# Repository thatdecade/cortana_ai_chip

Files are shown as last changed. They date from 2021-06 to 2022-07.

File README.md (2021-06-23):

# Cortana AI Chip
Neopixel animated cortana chip with USB display stand.

Blog Post: https://www.westaby.net/2021/06/cortana-data-chip-and-display-stand/

Kits for sale: https://www.etsy.com/shop/WestabyElectronics

https://user-images.githubusercontent.com/6401110/123125386-17de3000-d40e-11eb-948b-370709867ea7.MOV

## Instructions: 
Choose which version you want to make, Trinket or Wemos.  Then print the associated 3D files and wire it up.

More build notes on the related pages.

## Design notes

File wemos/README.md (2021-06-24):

# WORK IN PROGRESS!!!!

I have not built this version yet.

# Wemos Build Instructions

This folder is for building a Cortana AI Chip with an WEMOS D1 Mini dev board.

[IMAGE]

## Part List:
* WEMOS D1 Mini https://amzn.to/3qwWNKp
* Neopixel jewel https://amzn.to/3gKQ6ko
* Pushbutton https://amzn.to/3x0Akra
* Magnet Connectors [TBD]

* Silver PLA Filament https://amzn.to/3vN5HnV
* Gray Glitter PLA Filament https://amzn.to/3d2W3ab
* Transparent PLA Filament https://amzn.to/3xEOMFm

We are a participant in the Amazon Services LLC Associates Program, an affiliate advertising program designed to provide a means for us to earn fees by linking to Amazon.com and affiliated sites.

## 3D Printing:

The Cortana Data Chip’s 3D model was designed by Dylan Powell. I modified the Halo Cortana Chip to fit the neopixel jewel and magnet pin connector. Model is prescaled to 125%. Download: https://www.thingiverse.com/thing:4891701

I printed the Data Chip with 0.20 layer height as a color change job at 2.80mm. Dark grey and then Silver.

## Assembly and Wiring:
* WEMOS D0 to Neopixel Data In
* WEMOS D1 to Button LED
* WEMOS D2 to Button Switch

The magnet connector has straight pins (not solder cup friendly).  Recommend using some spare perfboard as a breakout or some 30 AWG Wrapping Wire around the pins using a wire wrap tool, then soldering.  More info: https://learn.sparkfun.com/tutorials/working-with-wire/how-to-use-a-wire-wrap-tool

Since the magnet connector is not keyed, it is possible to connect the cortana ai chip in backwards and reverse all the pins to the neopixel.  To prevent burnout, place the V+ pin in the center and a 100k ohm resistor on the data pin.  The breakout board in the pcb folder does this.

## Arduino:

TBD

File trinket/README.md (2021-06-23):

# Trinket Build Instructions

This folder is for building a Cortana AI Chip with an Adafruit Trinket Mini 5V dev board.

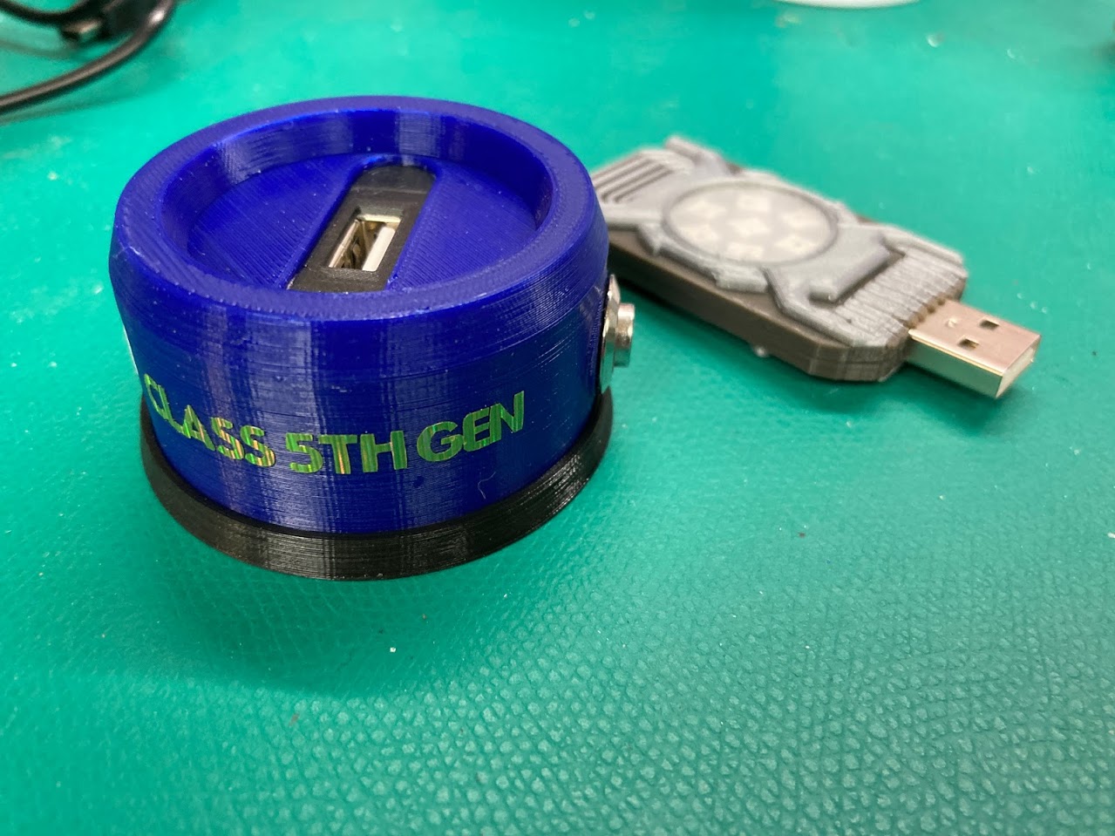
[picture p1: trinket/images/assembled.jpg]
 

## Part List:
* Adafruit trinket https://amzn.to/2SXYDr3
* Neopixel jewel https://amzn.to/3gKQ6ko
* Pushbutton https://amzn.to/3x0Akra
* USB Connectors https://amzn.to/3qiJgWt

* Silver PLA Filament https://amzn.to/3vN5HnV
* Gray Glitter PLA Filament https://amzn.to/3d2W3ab
* Transparent PLA Filament https://amzn.to/3xEOMFm

We are a participant in the Amazon Services LLC Associates Program, an affiliate advertising program designed to provide a means for us to earn fees by linking to Amazon.com and affiliated sites.

## 3D Printing:

The Cortana Data Chip’s 3D model was designed by Dylan Powell. I modified the Halo Cortana Chip to fit the neopixel jewel and usb plug. Model is prescaled to 125%. Download: https://www.thingiverse.com/thing:4891701

I printed the Data Chip with 0.20 layer height as a color change job at 2.80mm. Dark grey and then Silver.

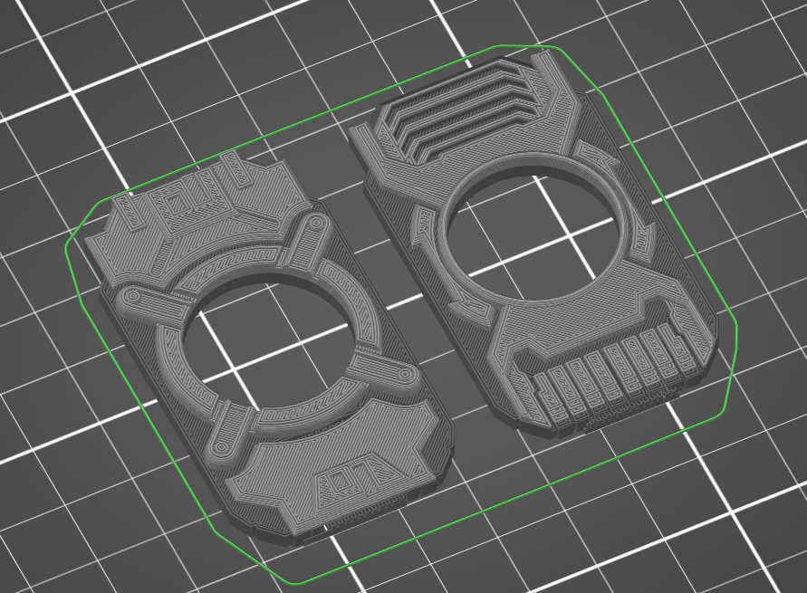
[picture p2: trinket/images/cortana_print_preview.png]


## Assembly and Wiring:
* Trinket #0 to Neopixel Data In
* Trinket #1 to Button LED
* Trinket #2 to Button Switch

I wired the neopixel through the USB socket.  V+ and GND I kept on pins 1 and 4, neopixel data wire on one of the data pins.  This ensures that if the USB is plugged into a real USB port, nothing will break.

## Arduino:
The code was based on an adafruit example for the trinket. I wrote about 10 animations, inspired by my previous energy sword builds.

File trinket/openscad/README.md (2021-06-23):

# Printing

You can print the objects as-is.  They are prescaled to 125% with cutouts for the USB and NeoPixel Jewel.

To remix using openscad, you will need the original objects from here: https://www.thingiverse.com/thing:1114763

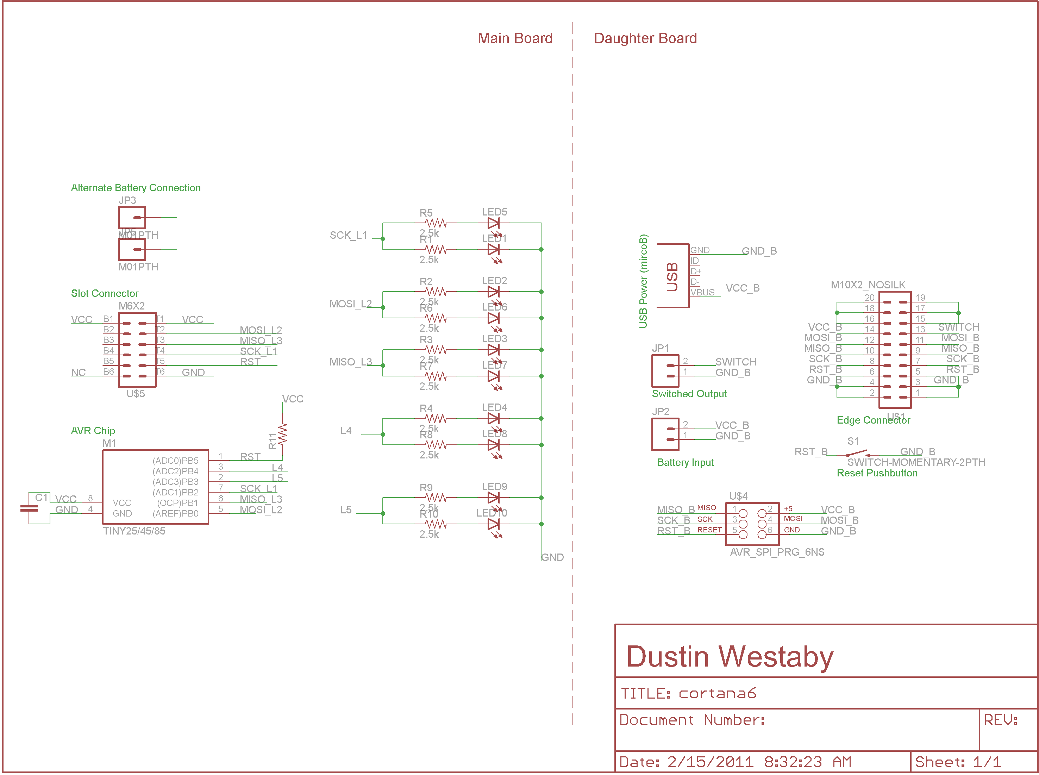
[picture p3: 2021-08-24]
attiny/schematic.png

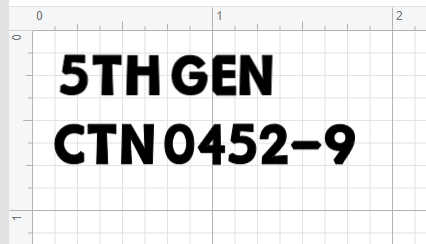
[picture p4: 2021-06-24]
trinket/images/stickers.png

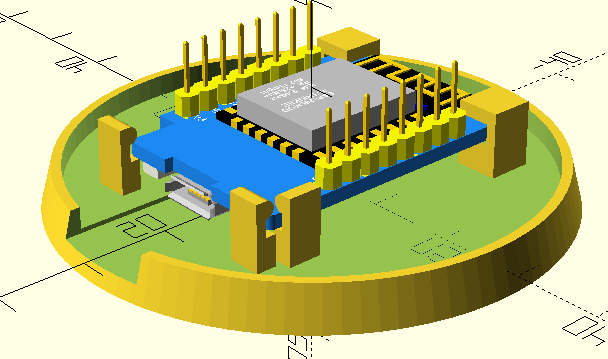
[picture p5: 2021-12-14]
wemos/openscad/cortana_stand_render_2.png

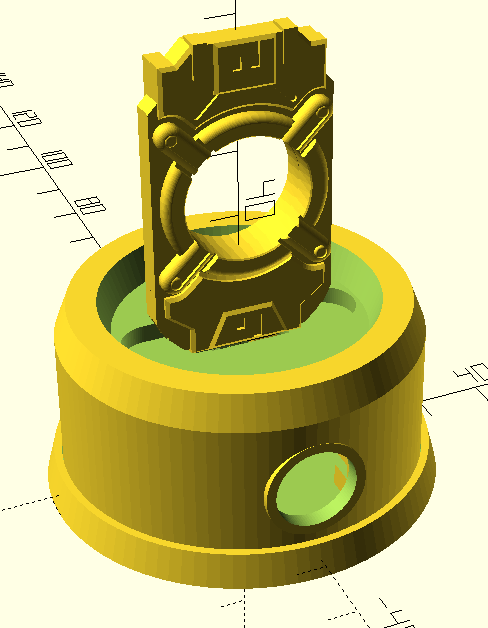
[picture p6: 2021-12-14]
wemos/openscad/cortana_stand_render_1.png

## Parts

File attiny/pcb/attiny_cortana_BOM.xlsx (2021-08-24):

Comment | Designator | Footprint | JLCPCB Part #（optional）
0.1uF | C2 | 0402 | C696352
10k ohm | R12 | 0402 | C25744
100 ohm | R1-11 | 0402 | C25076
Blue LED | LED1-10 | LED_0603 | C72041
Attiny45-20SU | U1 | 8-SOIC | C62689

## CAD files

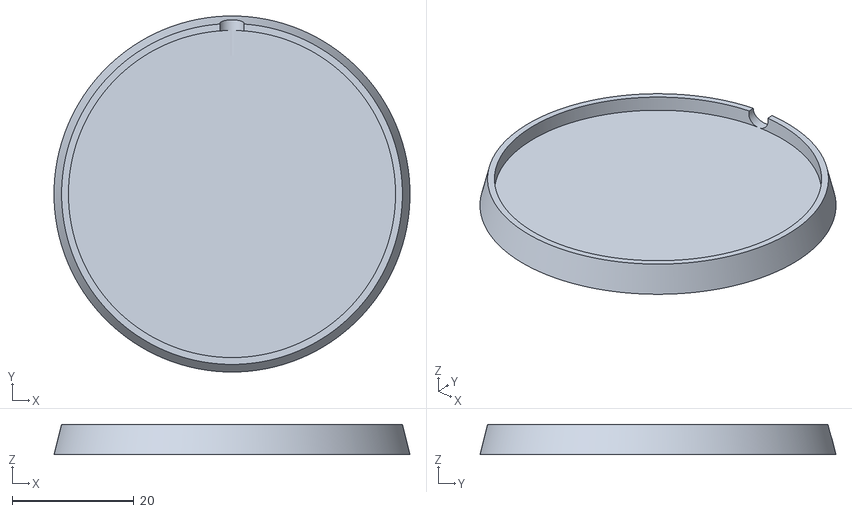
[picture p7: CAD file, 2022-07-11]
attiny/openscad/attiny_cortana_ai_chip_stand_bottom.stl
58.5 x 58.5 x 5.00

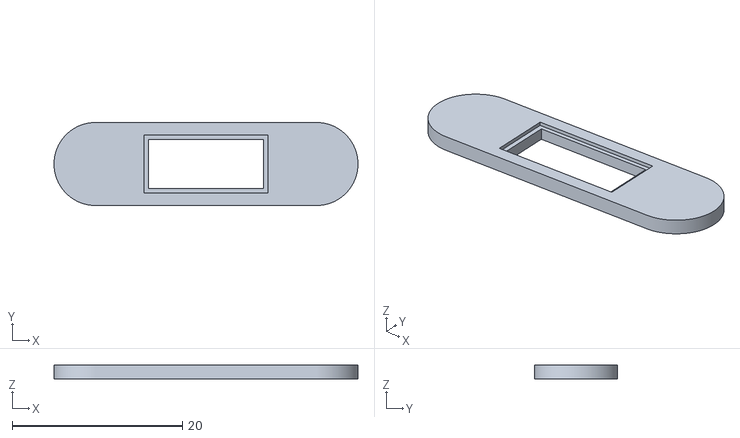
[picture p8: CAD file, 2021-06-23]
trinket/openscad/cortana_ai_chip_stand_usb_inset.stl
35.7 x 9.75 x 1.60

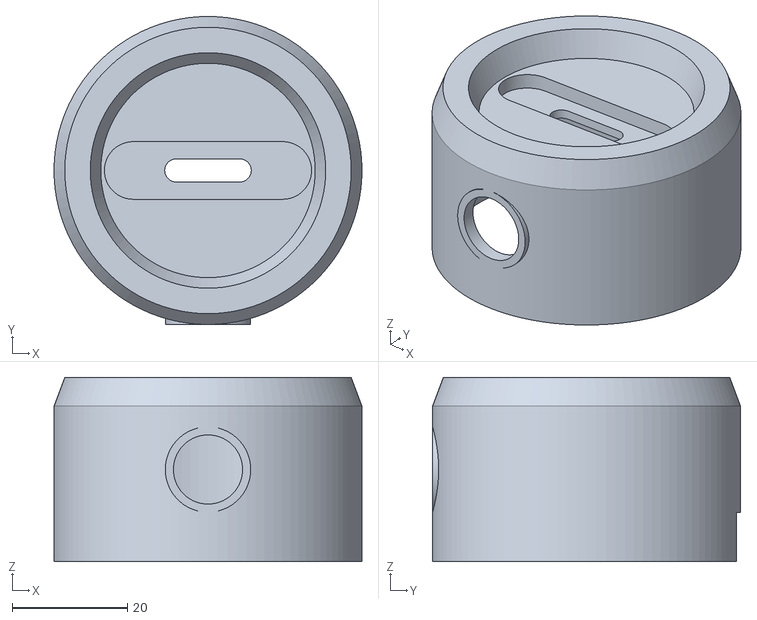
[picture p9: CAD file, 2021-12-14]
wemos/openscad/cortana_ai_chip_stand_top.stl
53.5 x 53.5 x 32.0

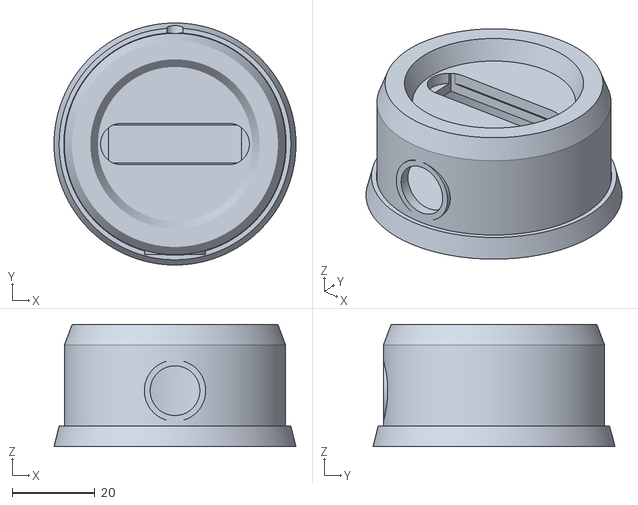
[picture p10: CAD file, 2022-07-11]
attiny/openscad/attiny_cortana_ai_chip_stand.stl
58.5 x 58.5 x 29.5

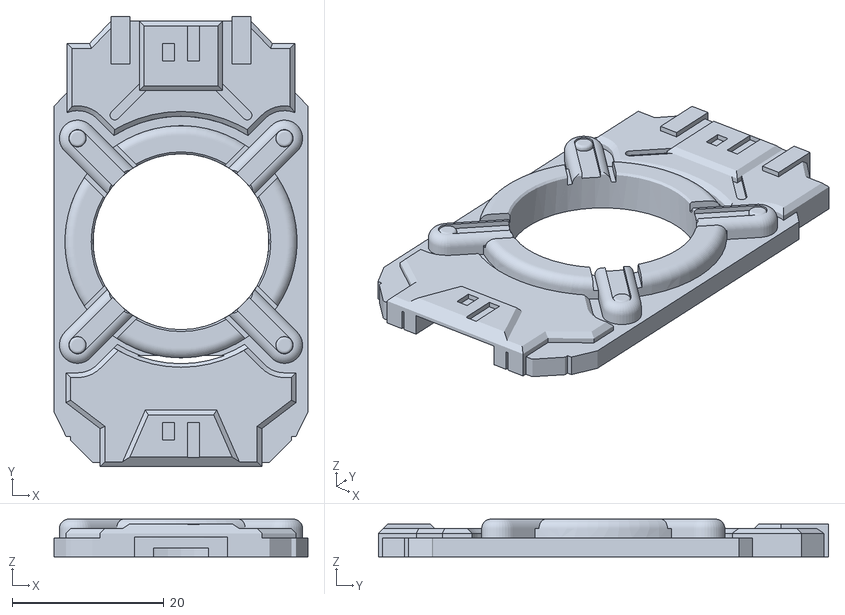
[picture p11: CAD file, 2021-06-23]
trinket/openscad/cortana_ai_chip_usb_125_scale_bottom.stl
33.5 x 59.3 x 5.00

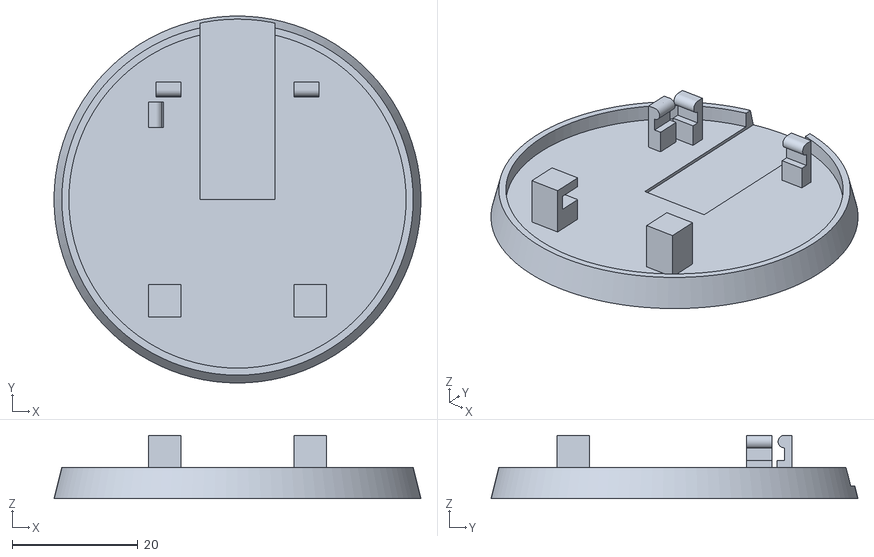
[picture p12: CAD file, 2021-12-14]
wemos/openscad/cortana_ai_chip_stand_bottom.stl
58.5 x 58.5 x 10.1

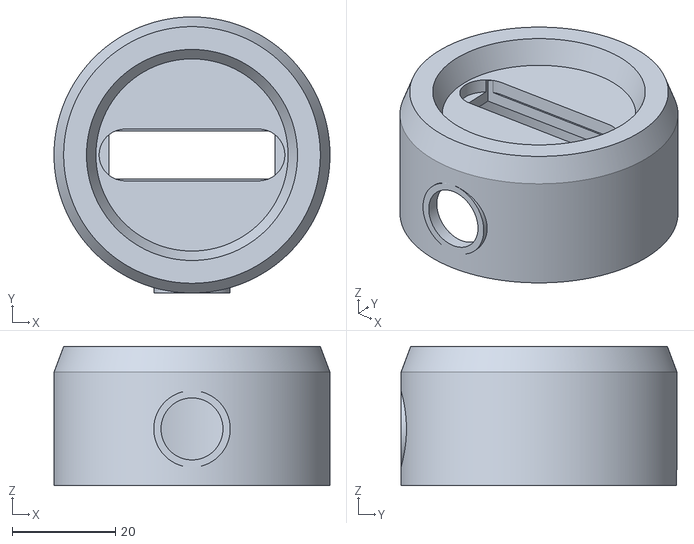
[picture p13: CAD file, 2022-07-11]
attiny/openscad/attiny_cortana_ai_chip_stand_top.stl
53.5 x 53.5 x 27.0

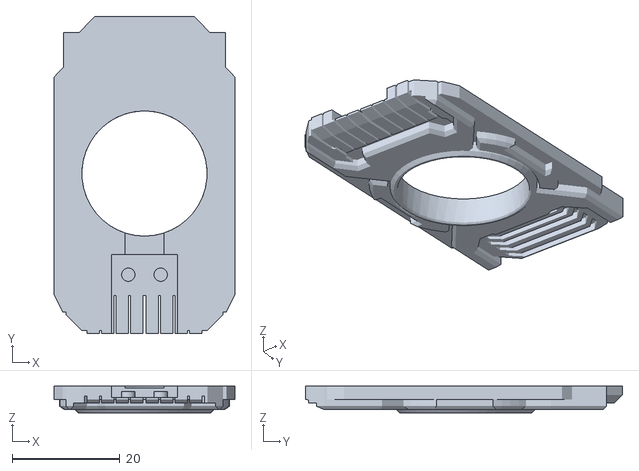
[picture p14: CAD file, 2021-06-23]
trinket/openscad/cortana_ai_chip_usb_125_scale_top.stl
33.5 x 58.7 x 5.00

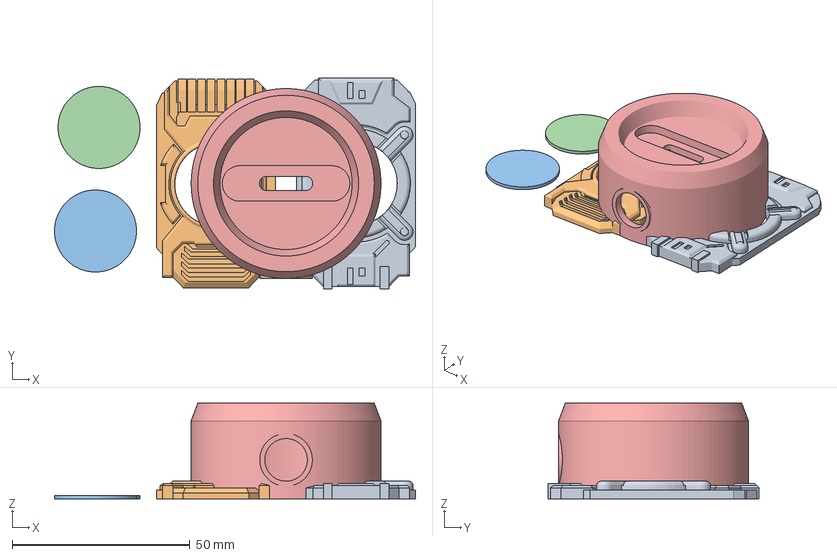
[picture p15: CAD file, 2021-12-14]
wemos/openscad/cortana_pogo_dual_color.3mf
101.7 x 59.3 x 27.0 mm
cortana_ai_chip_pogo_125_scale_TOP.stl
cortana_ai_chip_pogo_125_scale_bottom.stl
cortana_ai_chip_usb_125_scale_center_diffuser.stl x 2
cortana_ai_chip_stand.stl

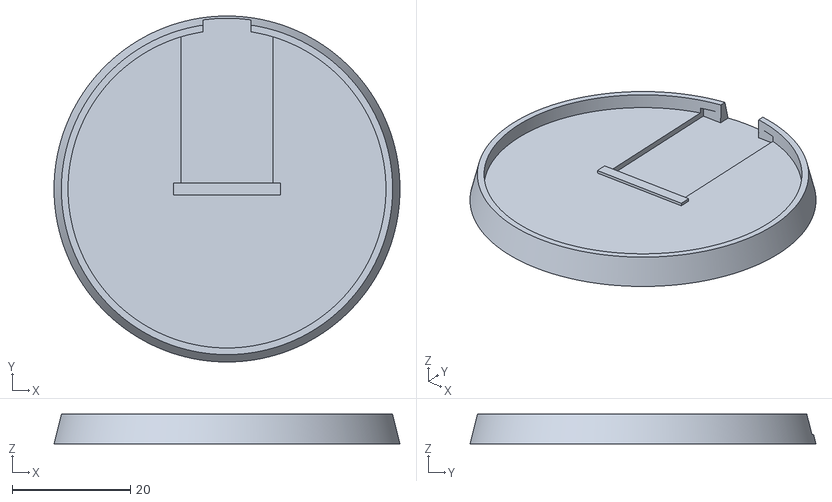
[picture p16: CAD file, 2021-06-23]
trinket/openscad/cortana_ai_chip_stand_bottom.stl
58.5 x 58.5 x 5.00

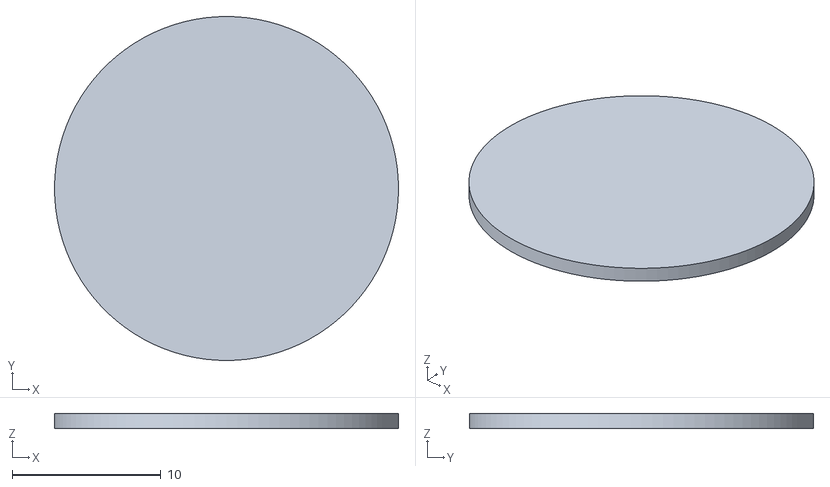
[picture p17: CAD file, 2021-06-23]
trinket/openscad/cortana_ai_chip_usb_125_scale_center_diffuser.stl
23.1 x 23.1 x 1.00

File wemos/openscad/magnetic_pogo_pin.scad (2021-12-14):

/* This is a cutout for a Magnet Pad Connector, 3 Pin, 2.54 Pitch.

   Includes the breakout pcb.

*/

/* ************************* */

$fn=50;

friction_fit = 0.02;
sliding_fit = 2;

/* ************************* */

//adjustments after printing once
print_adj_y = 1;
print_adj_flange_z = 0.2;
print_adj_flange_y = 1;


pogo_overall_y = 15 + friction_fit;
pogo_overall_x = 4 + friction_fit + print_adj_y;
pogo_overall_z = 4 + friction_fit;

flange_z = 0.8 + friction_fit + print_adj_flange_z;
flange_z_offset = 0.2;

edge_radius = 2;

pcb_x = 10.2 + sliding_fit;
pcb_y = pogo_overall_y; //9.9 actual
pcb_z = 1.6  + friction_fit;

connector_z_offset = pogo_overall_z/2 + pcb_z/2;
connector_x_offset = 2.54;

pogo_and_pcb_z_height = pcb_z + pogo_overall_z;

solder_connection_allowable_z = pogo_overall_z-1;
solder_connection_x = 2.54 * 1.2;

/* ************************* */

draw_pogo_magnet_and_pcb();

/* ************************* */

module draw_pogo_magnet_and_pcb(big_pcb=false)
{
    translate([0,0,pogo_overall_z/2+pcb_z])
    {
        spring_magnet();
        draw_pcb(big_pcb);
    }
}

module draw_pcb(big_pcb=false)
{
    translate([connector_x_offset, 0, -connector_z_offset + 0.01]) 
    {
    cube([pcb_x, pcb_y, pcb_z], center = true);
    
    if (big_pcb==false) translate([2.54,0,solder_connection_allowable_z/2]) cube([solder_connection_x,pcb_y,solder_connection_allowable_z], center = true);
    else translate([0,0,solder_connection_allowable_z/2]) cube([pcb_x,pcb_y,solder_connection_allowable_z+0.2], center = true);
    }
}

module spring_magnet()
{
    //flange
    translate([0,0,-0.2]) cube([pogo_overall_x,pogo_overall_y+print_adj_flange_y,flange_z], center=true);
    
    //body
    translate([0,pogo_overall_y/2-edge_radius,-pogo_overall_z/2]) cylinder(r=edge_radius, h=pogo_overall_z);
    translate([0,-pogo_overall_y/2+edge_radius,-pogo_overall_z/2]) cylinder(r=edge_radius, h=pogo_overall_z);
    translate([0,0,0]) cube([4,15-4,pogo_overall_z], center=true);
}

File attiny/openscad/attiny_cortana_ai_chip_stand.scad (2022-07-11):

/* ************************************************************* */
// Some easy constants
scale_multiplier = 1.25;//1.25; //match with cortana print

friction_fit = 0.2;
sliding_fit  = 2;

nozzle_diameter = 0.4;

$fn = 500;

shell_thickness = 2;
slot_depth = 4;

/* ************************************************************* */
// Measurements

slot_x = 26.76 + sliding_fit;
slot_y = 6 + sliding_fit;
slot_round_diameter = slot_y;

insert_x = 60;
insert_y = 60.66;
insert_height = 23.27;

base_diameter = slot_x + 14;
base_height = slot_depth + (17 / scale_multiplier);

inner_diameter = base_diameter - shell_thickness*2;

ridge_height = 4;
ridge_chamfer_diameter = base_diameter - 3;

outer_ridge_diameter = ridge_chamfer_diameter - 7;
inner_ridge_diameter = outer_ridge_diameter   - 3;

connector_x = (31.9 + friction_fit) / scale_multiplier;
connector_y = (9.07 + friction_fit) / scale_multiplier;

switch_hole_diameter = 12 / scale_multiplier;

/* ************************************************************* */
// Draw What?

//translate([-insert_x/2,-insert_y/2-1.7,0]) import("BackFanInsert_r1_3.stl");

draw_upper_shell();

draw_lower_shell();

//draw_cortana_reference();

//draw_ai_slot_insert();

//cord_hole("top");

/* ************************************************************* */
// Draw Parts


module cord_hole(section="bottom")
{
    translate([0,outer_ridge_diameter,ridge_height/2])
    {
        if (section=="top")
        {
            //widen
        translate([0,-10,-ridge_height/2])
            cube([4,10,4], center=true);
        }
        
        //slot
        rotate([90,0,0])
        cylinder(d=4, h=10);
    }
}
module draw_trinket()
{
    trinket_width = 27.1 + friction_fit;
    trinket_height = 15.36 + friction_fit;
    trinket_depth = 1.72 + friction_fit;
    trinket_inset = 4;

    usb_width  = 7.92 + friction_fit;
    usb_height = 8.37 + sliding_fit;
    usb_depth  = 3.4 + friction_fit;
    
    trinket_to_wall_thickness = nozzle_diameter * 2;

    rotate([0,0,90])
    translate([-trinket_to_wall_thickness,-trinket_height/2,-trinket_depth/2])
    union()
    {
        cube([trinket_width,trinket_height,trinket_depth]);
        translate([trinket_width-usb_height,trinket_height/2-usb_width/2,0]) cube([usb_height+trinket_inset,usb_width,usb_depth]);
    }
}

module draw_lower_shell()
{
    scale(scale_multiplier)
    union()
    {
        //bottom
        difference()
        {
            translate([0,0,0]) cylinder (h = shell_thickness * 2, d1=base_diameter + shell_thickness*2, d2=base_diameter + shell_thickness, center = true);
            translate([0,0,shell_thickness/2 + 0.01]) cylinder (h = shell_thickness, d=base_diameter + friction_fit, center = true);
            
            //back port
            scale(1 / scale_multiplier) cord_hole(section="bottom");
        }
        
        //cool details
        //TBD
        
        //trinket capture ledge
        //capture_height = 0.5;
        //scale(1 / scale_multiplier) translate([0,0,capture_height/2]) cube([18,2,capture_height], center=true);
        
        
    }
}

module draw_ai_slot_insert()
{
    z_offset = base_height-slot_depth/2 + shell_thickness;
    
    usb_rim_depth = 0.78 + friction_fit;
    slot_depth = (0.5 + usb_rim_depth) / scale_multiplier;
    
    slot_x_new = slot_x - friction_fit;
    slot_y_new = slot_y - friction_fit;
    slot_round_diameter_new = slot_round_diameter - friction_fit;
    
    usb_rim_x = (14.37+friction_fit)/scale_multiplier;
    usb_rim_y = (6.58+friction_fit)/scale_multiplier;
    
    scale(scale_multiplier)
    difference()
    {
        //slot
        union()
        {
            translate([0,0,z_offset]) cube([slot_x_new - slot_round_diameter_new, slot_y_new, slot_depth + 0.1], center=true);
            translate([-slot_x_new/2+slot_round_diameter_new/2,0,z_offset]) cylinder (h = slot_depth + 0.1, d=slot_round_diameter_new, center = true);
            translate([+slot_x_new/2-slot_round_diameter_new/2,0,z_offset]) cylinder (h = slot_depth + 0.1, d=slot_round_diameter_new, center = true);
        }
    
        //usb port
        translate([0,0,z_offset])  cube([connector_x, connector_y, slot_depth + 0.1 +0.01], center = true);
        
        //usb rim
        translate([0,0,z_offset+usb_rim_depth])  cube([usb_rim_x, usb_rim_y, slot_depth + 0.1 +0.01], center = true);
    }
        
}

module draw_ai_slot()
{
    z_offset = base_height-slot_depth/2 + shell_thickness;
    
    //slot
    translate([0,0,z_offset]) cube([slot_x - slot_round_diameter, slot_y, slot_depth + 0.1], center=true);
    translate([-slot_x/2+slot_round_diameter/2,0,z_offset]) cylinder (h = slot_depth + 0.1, d=slot_round_diameter, center = true);
    translate([+slot_x/2-slot_round_diameter/2,0,z_offset]) cylinder (h = slot_depth + 0.1, d=slot_round_diameter, center = true);
    
    //usb port
    translate([0,0,z_offset - shell_thickness])  cube([connector_x, connector_y, slot_depth + 0.1], center = true);
}

module draw_cortana_reference()
{
    translate([0,0,32]) rotate([90,0,0]) 
    union()
    {
        translate([0,0,0]) rotate([0,180,0]) import("Cortana_Chip_Assembly_-_Cortana_Chip_Top-2.STL");
        translate([0,0.5,0]) rotate([0,0,0]) import("Cortana_Chip_Assembly_-_Cortana_Chip_Bottom.STL");
    }
}

module draw_switch_cyl(diameter)
{
    hole_depth = shell_thickness*2;
    
    //switch_hole_diameter
    translate([0,-inner_diameter/2+hole_depth/2-0.01,base_height/2]) rotate([90,0,0]) cylinder(h=hole_depth, d=diameter);
}

module draw_switch_outline()
{
    switch_outline_pad = 2.25;
    draw_switch_cyl(switch_hole_diameter+switch_outline_pad);
}

module draw_switch_holes()
{
    translate([0,-0.01,0]) draw_switch_cyl(switch_hole_diameter);
    translate([0,2,0]) draw_switch_cyl(switch_hole_diameter+4);
}

module draw_upper_shell()
{
    
    scale(scale_multiplier)
    difference()
    {
        union()
        {
            draw_base();
            draw_switch_outline();
        }
        
        //bottom cutaway
        translate([0,0,base_height/2 - slot_depth]) cylinder (h = base_height + 0.2, d=inner_diameter, center = true);
        
        //ai slot
        draw_ai_slot();
        
        //back slot
        translate([0,0,-0.01]) scale(1 / scale_multiplier) cord_hole(section="top");
        
        //switch hole
        draw_switch_holes();
    }
    
        //scale(scale_multiplier) draw_switch_hole();
    
        //flatten side
    
        // button
}

module draw_base()
{
    //base
    translate([0,0,base_height/2]) cylinder (h = base_height, d=base_diameter, center = true);
    //ridge
    difference()
    {
        translate([0,0,base_height + ridge_height/2]) cylinder (h = ridge_height, d1=base_diameter, d2=ridge_chamfer_diameter, center = true);
        
        translate([0,0,base_height + ridge_height/2 + 0.1]) cylinder (h = ridge_height, d1=inner_ridge_diameter, d2=outer_ridge_diameter, center = true);
    }
}

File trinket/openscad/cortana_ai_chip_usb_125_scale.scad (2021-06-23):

/* Cortana Data Chip w/ Circuits

Author: Dustin Westaby

This cortana data chip uses a Neopixel jewel, arduino trinket, and a female USB socket.
*/
/* ***************************************************** */
scale_multiplier = 1.25;

sliding_fit = 2;
friction_fit = 0.2;

/* ***************************************************** */
overall_height = 58.57;
overall_width  = 33.37;
overall_depth  = 5.1;

center_diam = 22.8;

neo_ring_diam = 22.9 + friction_fit;
neo_ring_height = 0.8 + friction_fit;

/* ***************************************************** */
draw_shells();
//draw_center_ring(neo_ring_diam, overall_depth-neo_ring_height);

/* ***************************************************** */
module draw_usb_socket()
{
    overhang_x = 12;
    usb_male_x = 14.83 + friction_fit + overhang_x;
    usb_male_y = 12    + friction_fit;
    usb_male_z = 4.55  + friction_fit;
    
    usb_inset_holes_diameter = 2.67 - friction_fit;
    usb_inset_hole_spacing = 3;
    usb_inset_hole_edge_offset = 2.5;
    usb_inset_hole_height = 1.2;
    
    //this is a male socket
    difference()
    {
        //outline
        union()
        {
            //connector
            translate([-overhang_x/2,0,usb_male_z/2]) cube([usb_male_x, usb_male_y, usb_male_z], center=true);
            
            //wire channels
            translate([7.5,-(usb_male_y-5)/2,1.75]) cube([4,usb_male_y-5,1.5]);
        }
        
        //holes
        translate([
        usb_inset_hole_edge_offset+usb_inset_holes_diameter/2,
        usb_inset_hole_spacing,
        -0.1]) cylinder($fn=100, d=usb_inset_holes_diameter, h=usb_inset_hole_height);
        
        translate([
        usb_inset_hole_edge_offset+usb_inset_holes_diameter/2,
        -usb_inset_hole_spacing,
        -0.1]) cylinder($fn=100, d=usb_inset_holes_diameter, h=usb_inset_hole_height);
    }
    
}

module draw_center_ring(d, z)
{
    translate([0,0.25,z]) cylinder($fn=100, d=neo_ring_diam, h=neo_ring_height);
}

module draw_shells()
{
    difference()
    {
        union()
        {
            translate([0,0,overall_depth]) rotate([0,180,0]) scale(scale_multiplier) import("Cortana_Chip_Assembly_-_Cortana_Chip_Top-2.STL");
            //translate([0,0.32,overall_depth]) rotate([0,0,0]) scale(scale_multiplier) import("Cortana_Chip_Assembly_-_Cortana_Chip_Bottom.STL");
        }
        
        //neoring
        draw_center_ring(neo_ring_diam, overall_depth-neo_ring_height);
        
        //usb
        translate([0,-20-2.2,3]) rotate([0,0,90]) draw_usb_socket();
    }
}

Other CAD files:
trinket/openscad/cortana_ai_chip_stand_top.stl
trinket/openscad/cortana_ai_chip_stand.scad
wemos/openscad/cortana_ai_chip_stand.scad

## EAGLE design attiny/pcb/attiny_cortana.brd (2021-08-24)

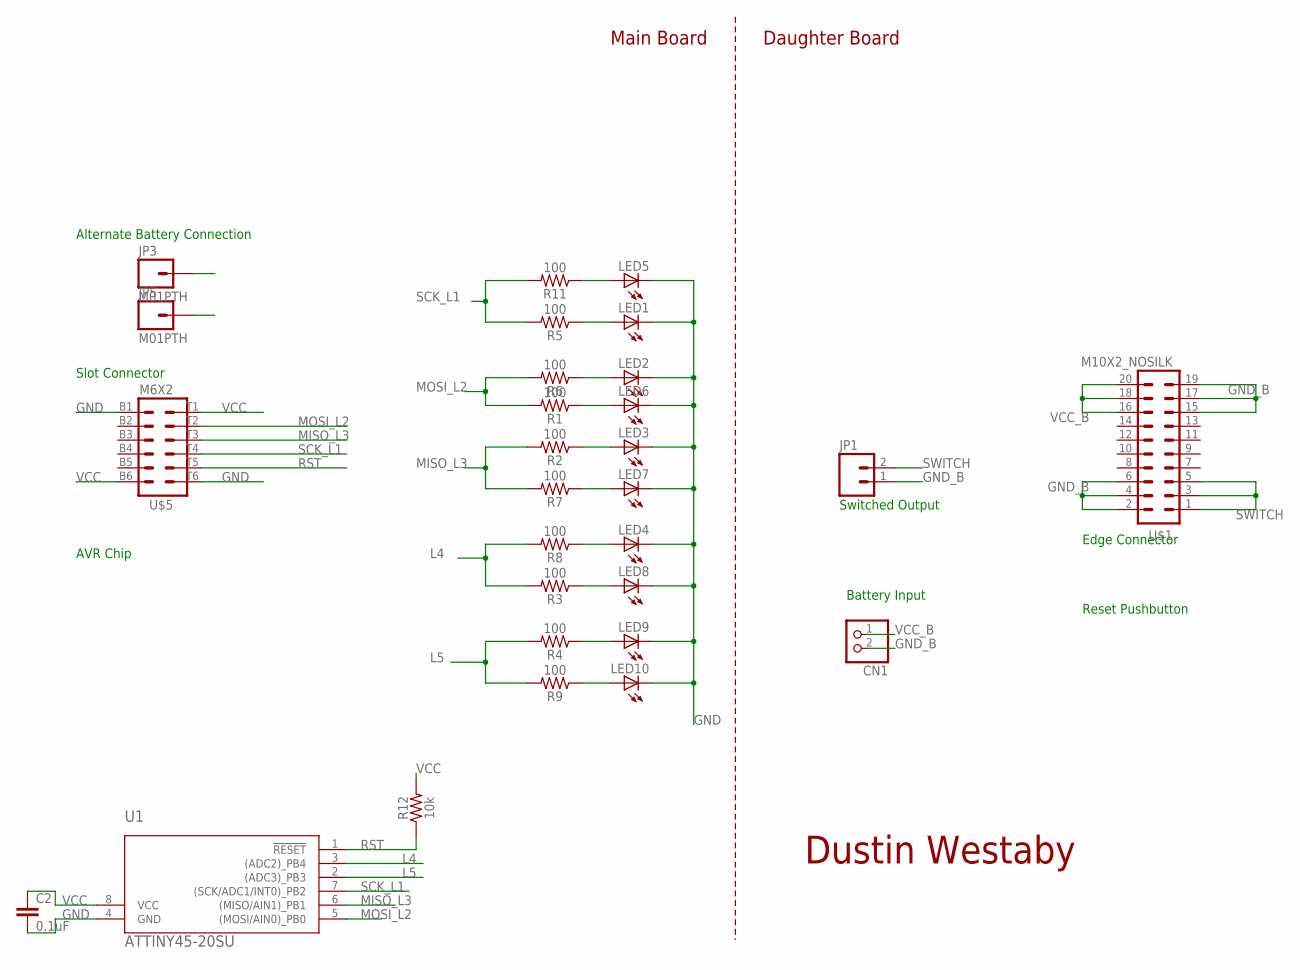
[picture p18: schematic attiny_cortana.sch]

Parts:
C2: 0.1uF; 0402-TIGHT
CN1: JST_2PIN-THM-RA; JST-PH-2-THM-RA
JP1: M02PTH; 1X02
JP3, JP5: M01PTH; 1X01
LED1, LED2, LED3, LED4, LED5, LED6, LED7, LED8, LED9, LED10: LED0603; LED-0603
R1, R2, R3, R4, R5, R6, R7, R8, R9, R11: 100; 0402-TIGHT
R12: 10k; 0402-TIGHT
U1: ATTINY45-20SU; 8S2_ATM
U$1: M10X2_NOSILK; 2X10_NOSILK
U$5: M6X2; CRT_CON

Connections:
GND: C2.2, JP5.1, LED1.C, LED2.C, LED3.C, LED4.C, LED5.C, LED6.C, LED7.C, LED8.C, LED9.C, LED10.C, U1.4 (GND), U$5.B1 (1), U$5.T6 (12)
GND_B: CN1.2 (1), JP1.1, U$1.2, U$1.4, U$1.6, U$1.15, U$1.17, U$1.19
L4: R3.2, R8.2, U1.3 ((ADC2)_PB4)
L5: R4.2, R9.2, U1.2 ((ADC3)_PB3)
MISO_L3: R2.2, R7.2, U1.6 ((MISO/AIN1)_PB1), U$5.T3 (9)
MOSI_L2: R1.2, R6.2, U1.5 ((MOSI/AIN0)_PB0), U$5.T2 (8)
unnamed: LED3.A, R2.1
unnamed: LED4.A, R8.1
unnamed: LED1.A, R5.1
unnamed: LED6.A, R1.1
unnamed: LED2.A, R6.1
unnamed: LED5.A, R11.1
unnamed: LED7.A, R7.1
unnamed: LED8.A, R3.1
unnamed: LED9.A, R4.1
unnamed: LED10.A, R9.1
RST: R12.1, U1.1 (!RESET), U$5.T5 (11)
SCK_L1: R5.2, R11.2, U1.7 ((SCK/ADC1/INT0)_PB2), U$5.T4 (10)
SWITCH: JP1.2, U$1.1, U$1.3, U$1.5
VCC: C2.1, JP3.1, R12.2, U1.8 (VCC), U$5.B6 (6), U$5.T1 (7)
VCC_B: CN1.1 (2), U$1.16, U$1.18, U$1.20

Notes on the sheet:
Dustin Westaby
Slot Connector
Switched Output
Battery Input
Daughter Board
Main Board
Alternate Battery Connection
AVR Chip
Reset Pushbutton
Edge Connector

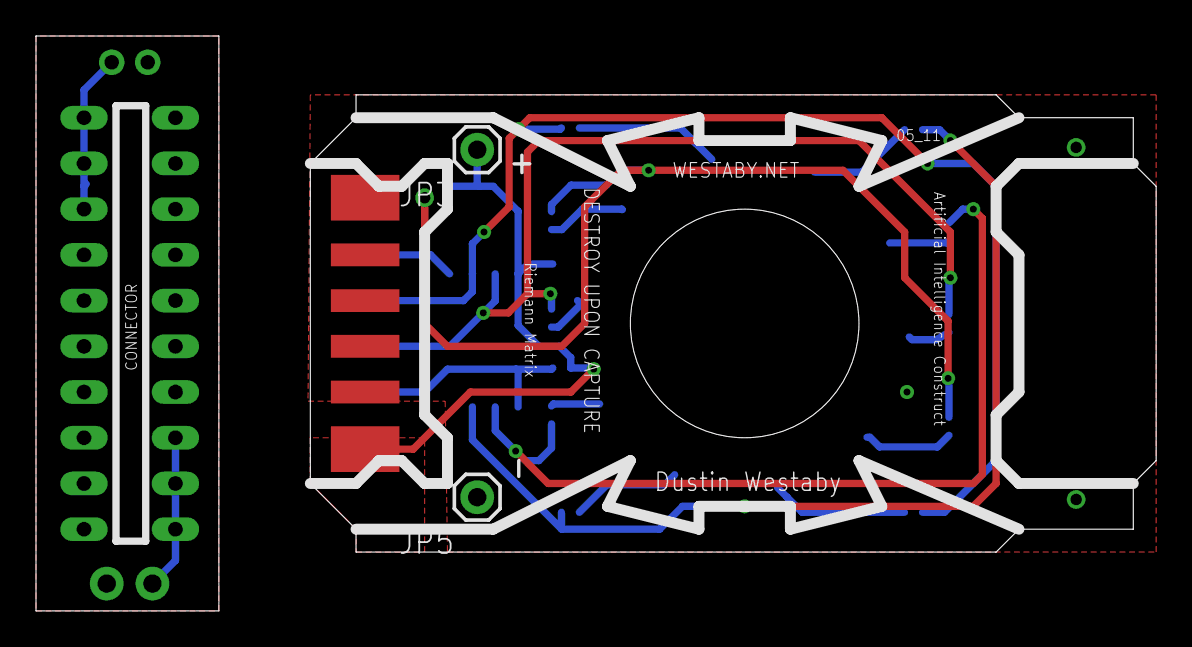
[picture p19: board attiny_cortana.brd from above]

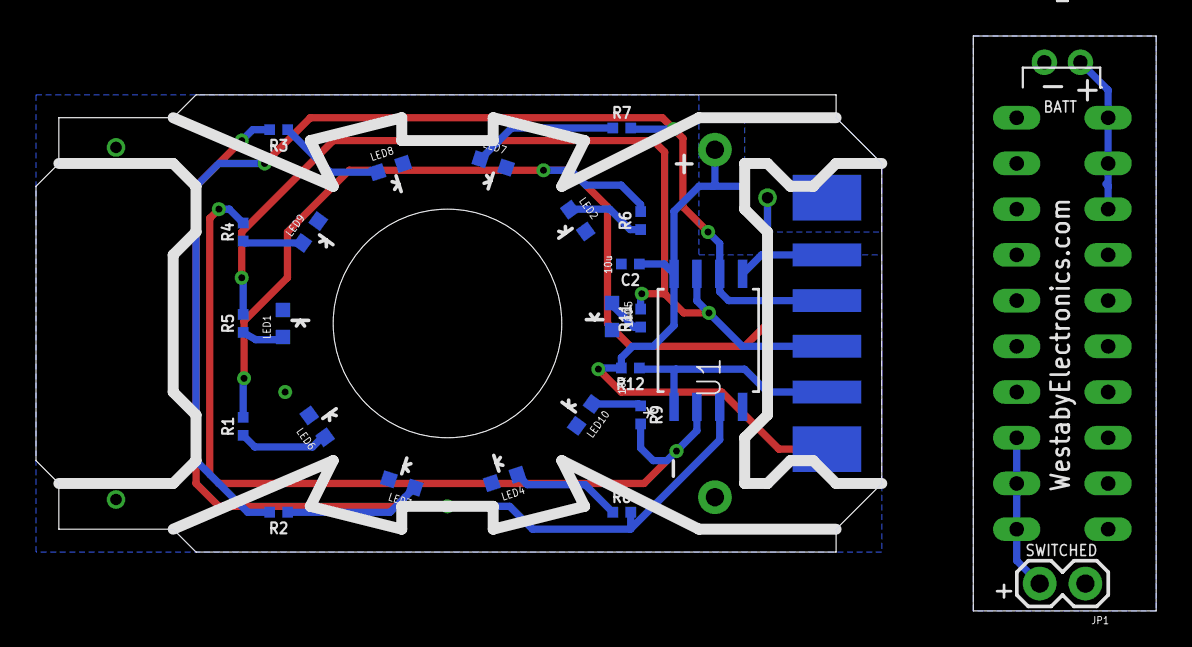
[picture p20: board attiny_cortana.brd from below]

Board: 2 copper layers, 47.0 x 25.4 mm, 29 parts (26 on the bottom side), 21 nets.

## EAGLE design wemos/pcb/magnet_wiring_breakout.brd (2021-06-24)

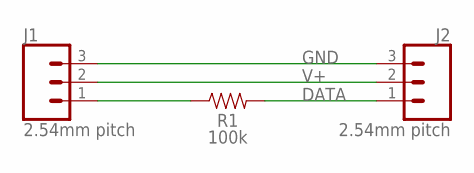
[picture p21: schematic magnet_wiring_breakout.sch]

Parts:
J1, J2: 2.54mm pitch; 1X03
R1: 100k; 0805

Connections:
DATA: J2.1, R1.2
GND: J1.3, J2.3
unnamed: J1.1, R1.1
V+: J1.2, J2.2

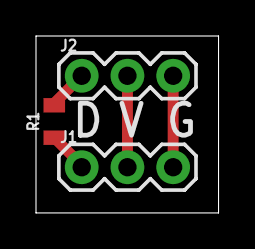
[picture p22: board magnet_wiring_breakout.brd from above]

Board: 2 copper layers, 10.1 x 9.8 mm, 3 parts (0 on the bottom side), 4 nets.

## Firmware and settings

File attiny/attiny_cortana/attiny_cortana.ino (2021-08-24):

/*

Cortana Arduino Code for the ATTiny45 by Dustin Westaby

Version History:
 2/13/11 Initial Draft and test circuit
 2/14/11 Updated Comments, re-arranged structure
 9/17/11 Timer Off Code Added
 9/27/12 converted to arduino, expanded animations (Ryuuzaki Julio)
11/29/12 cleaned up and rewrote logic

Ouputs:
 pin    label   connections
  2     PB3 =   LED
  3     PB4 =   LED
  5     PB0 =   LED
  6     PB1 =   LED
  7     PB2 =   LED
*/

#include <util/delay.h>

//arduino specific digital pin numbers
int myPins[6] = {2,3,4,1,0};

//performs subtraction then ensures positive result
#define ABS_SUB(a, b) ((a) < (b)? ((b) - (a)): ((a) - (b)))

/* -------------------- */
/* Helper Functions     */
/* -------------------- */

// the setup routine runs once when you press reset:
void setup()
{
   int i;

   // initialize the digital pin as an output.
   for (i=0;i<=4;i++)
   {
      pinMode(myPins[i], OUTPUT);
   }

}

void delay_ms(uint16_t ms)
{
   while ( ms )
   {
      _delay_ms(1);
      ms--;
   }
}

void delay_us(uint16_t us)
{
   while ( us )
   {
      _delay_us(1);
      us--;
   }
}

/* -------------------- */
/* Animation Functions  */
/* -------------------- */

void blinkBlink(int delayTime, int MaxFlickr)
{
   int i, RandomFlickrAmmount;

   //randomize number of blinks and delay to help blinking look more alive
   RandomFlickrAmmount = random(1,MaxFlickr);

   for (i = 0; i <= RandomFlickrAmmount; i++)
   {
      //Turn ON all LEDs 01234
      PORTB = 0b00011111;
      delay(delayTime - RandomFlickrAmmount);

      //Turn OFF all LEDs 01234
      PORTB = 0b00000000;
      delay(delayTime - RandomFlickrAmmount);
   }

} //end blink function

void spinSpin(int count_delay)
{
   int i;
   int repeat           = random(1,3)*5;    //random number of spins times 5 LEDs
   int circle_direction = random(0,1);      //random selection of clockwise or counterclockwise animations
   int pin_to_on  = random(0,4);            //random starting LED position for animation (on)
   int pin_to_off = random(0,4);            //random starting LED position for animation (off)

   //loop ends after random number of spins
   for (i = 0; i <= repeat; i++)
   {
      if (circle_direction == 1)
      {
         //each animation section turns off one LED and turns on one LED
         digitalWrite(myPins[pin_to_on++], HIGH);
         digitalWrite(myPins[pin_to_off++], LOW);
      }
      else
      {
         //each animation section turns off one LED and turns on one LED
         digitalWrite(myPins[pin_to_on--], HIGH);
         digitalWrite(myPins[pin_to_off--], LOW);
      }

      //delay before next spin animation
      delay(count_delay);

      //the following overrun check works because circle_direction can only be 0 or 1.
      //When circle_direction is 0, the pin_to_on pin_to_off are decremented, down to 0.  The overrun check compares to 0, then sets to 4.
      //When circle_direction is 1, the pin_to_on pin_to_off are incremented, up to 4.  The overrun check compares to 4, then sets 0.
      if (pin_to_on == circle_direction*4)
      {
         pin_to_on = ABS_SUB(circle_direction*4,4);
      }
      if (pin_to_off == circle_direction*4)
      {
         pin_to_off = ABS_SUB(circle_direction*4,4);

         //one rotation complete
         //speed up the spinning, down to 16
         if (count_delay > 16)
         {
            count_delay = count_delay - 2;
         }
      }

   } //end loop

} //end spin function

/* -------------------- */
/* Main Function        */
/* -------------------- */

void loop()
{
   int i = 0;
   int count_delay, e, repeat;
   int time_on, time_off, max_value, min_value, rate_of_change;
   boolean fade_direction;
   int Chances_of_Flickr;
   int Chances_of_Spin;
   int X_Loops;
   int randomInt;

   /* Set output pins */
   DDRB = 0b00011111;

   /* ---------------------------------------------------------------- */
   /* All OFF Short */
   /* ---------------------------------------------------------------- */

   count_delay = 20; //Delay starting point
   for (i = 0; i <= 4; i++)
   {
      digitalWrite(myPins[i], LOW);  //turn off each of the 4 LEDs in sequence
      delay(count_delay*2 + i*20);   //delay increases after each iteration
   }

   /* ---------------------------------------------------------------- */
   /* Spin Circle (single runner) */
   /* ---------------------------------------------------------------- */

   repeat = 8;       //Number of spins
   count_delay = 60; //Delay between circle movement in ms

   for(e = 0; e <= repeat; e++)
   {
      for (i = 0; i <= 4; i++)
      {
         digitalWrite(myPins[i], HIGH);
         delay(count_delay);
         digitalWrite(myPins[i], LOW);
      }

      if (count_delay >= 6)
      {
         count_delay = count_delay - 6;
      }
   }

   /* ---------------------------------------------------------------- */
   /* Spin Circle (chased runner) */
   /* ---------------------------------------------------------------- */

   spinSpin(16);  //spin with constant speed of 16ms

   /* ---------------------------------------------------------------- */
   /* All ON Long */
   /* ---------------------------------------------------------------- */

   count_delay = 20; //Delay starting point

   for (i = 0; i <= 4; i++)
   {
      digitalWrite(myPins[i], HIGH);  //turn on each of the 4 LEDs in sequence
      delay(count_delay*2 + i*20);    //delay increases after each iteration
   }
   delay(200);

   /* ---------------------------------------------------------------- */
   /* Blink Blink */
   /* ---------------------------------------------------------------- */

   blinkBlink(50,5);
   delay_ms(100);
   blinkBlink(50,2);
   delay(200);

   /* ---------------------------------------------------------------- */
   /* Fade In and Out Continuous (Software PWM) */
   /* ---------------------------------------------------------------- */

   max_value = 400;           //Max for LEDs ON in us
   min_value = 3;             //Max for LEDs OFF in us
   time_on  = min_value;      //Set Starting Time ON to min
   time_off = max_value;      //Set Starting Time OFF to max
   rate_of_change = 1;        //This is the speed that the fade goes between min and max
   fade_direction = false;    //Direction is defined for the direction of the fade (in or out)
   Chances_of_Flickr = 2;     //The breathing animation has 2 in X_Loops chances of flickering.
   Chances_of_Spin   = 1;     //The breathing animation has 1 in X_Loops chances of Spining.
   X_Loops = 3000;

   while(true) // Repeat Forever
   {

      //Turn ON all LEDs 01234
      PORTB = 0b00011111;
      delay_us(time_on);

      //Turn OFF all LEDs 01234
      PORTB = 0b00000000;
      delay_us(time_off);

      if (fade_direction==true)
      {
         //In the UP direction the Time ON increases while the Time OFF decreases.
         //The result is that the LEDs get brighter
         time_on  += rate_of_change;
         time_off -= rate_of_change;

         //When the end of the fade is reached, switch directions
         if (time_on>max_value)
         {
            fade_direction = false;
         }
      }
      else
      {
         //In the DOWN direction the Time ON decreases while the Time OFF increases.
         //The result is that the LEDs get dimmer
         time_on  -= rate_of_change;
         time_off += rate_of_change;

         //When the end of the fade is reached, switch directions
         if (time_on <= min_value)
         {
            fade_direction=true;
         }
      }

      //Throughout the sequence, random chance of blinking or spinning instead of normal fading
      randomInt= random(1, X_Loops);
      if (randomInt <= Chances_of_Flickr)
      {
         blinkBlink(15, 4);
      }

      if (randomInt >= X_Loops-Chances_of_Spin)
      {
         spinSpin(30);  //spin with increasing speed, from 20 to 16ms
      }

   } //end inf loop

} // end main loop

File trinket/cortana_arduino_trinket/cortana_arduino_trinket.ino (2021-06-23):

// Low power NeoPixel goggles example.  Makes a nice blinky display
// with just a few LEDs on at any time.
#include <EEPROM.h>
#include <Adafruit_NeoPixel.h>
#ifdef __AVR_ATtiny85__ // Trinket, Gemma, etc.
 #include <avr/power.h>
#endif

#define NEO_PIN 0
#define LED_PIN 1
#define BUTTON_PIN 2

Adafruit_NeoPixel pixels = Adafruit_NeoPixel(7, NEO_PIN);

#define RED  0xFF0000
#define BLUE 0x0025FF

typedef enum
{
  SPARK_MODE = 0,
  SETUP_SPIN_FADE_RED_TO_BLUE,
  SPINNING_MODE_FADE_RED_TO_BLUE,
  BREATHING_ENERGY,
  INFECTED_SPINNING,
  INFECTED_BREATHING,
  FIRE_SPINNING,
  FIRE_BREATHING,
  GRUNT_BIRTHDAY_FAST,
  GRUNT_BIRTHDAY_SLOW,
  MAX_MODE
};

uint8_t  mode   = SETUP_SPIN_FADE_RED_TO_BLUE; // Startup animation effect
         
void setup() 
{
#ifdef __AVR_ATtiny85__ // Trinket, Gemma, etc.
  if(F_CPU == 16000000) clock_prescale_set(clock_div_1);
#endif
  pixels.begin();
  pixels.setBrightness(85); // 1/3 brightness

  pinMode(BUTTON_PIN, INPUT_PULLUP);
  pinMode(LED_PIN, OUTPUT);

  digitalWrite(LED_PIN, HIGH);
  
  randomSeed(analogRead(A0));  // make sure nothing is connected to A0 so that random noise acts as seed
}

void loop() 
{
  uint32_t t;
  static byte r_color = 0;
  static byte g_color = 0;
  static byte b_color = 0;
  
  
  static byte brightness = 85;
  static bool dim_direction = false;
  
  static uint32_t primary_mix = 20;
  static uint32_t secondary_mix = 100;
  static bool mix_direction = false;

  boolean newState = digitalRead(BUTTON_PIN);
  static boolean oldState = HIGH;

  // Check if state changed from high to low (button press).
  if((newState == LOW) && (oldState == HIGH)) 
  {
    delay(20);
    // Check if button is still low after debounce.
    newState = digitalRead(BUTTON_PIN);
    if(newState == LOW) 
    {
      pixels.clear();
      if(++mode >= MAX_MODE) 
      {
        mode = 0;
      }
    }
  }
  oldState = newState;
  
  //update color mixes
  primary_mix   = get_fade_value(&mix_direction, primary_mix, 1, 20, 100);
  secondary_mix = 101 - primary_mix;
  if(secondary_mix < 1)
  {
    secondary_mix = 1;
  }
  
  //run requested animation
  switch(mode)
  {
    case GRUNT_BIRTHDAY_FAST:
      rainbow();
      delay(2);
      break;
    case GRUNT_BIRTHDAY_SLOW:
      rainbow();
      delay(20);
      break;
    case SETUP_SPIN_FADE_RED_TO_BLUE:
      r_color = 255;
      g_color = 0;
      b_color = 0;
      mode = SPINNING_MODE_FADE_RED_TO_BLUE;
      break;
    case SPINNING_MODE_FADE_RED_TO_BLUE:
      if (b_color < 250)
      {
        r_color -= 10;
        b_color += 10;
      }
      spin_animation(((uint32_t)r_color << 16) + ((uint32_t)g_color >> 8) + b_color);
      break;
      
     case BREATHING_ENERGY:
      brightness = get_fade_value(&dim_direction, brightness, 1, 10, 85);

      pixels.fill(pixels.Color(primary_mix, secondary_mix, 222));
      pixels.setBrightness(brightness);
      pixels.show();
      delay(30);
      break;

     case INFECTED_SPINNING:
      spin_animation(pixels.Color(primary_mix, 222, secondary_mix));
      break;
     case INFECTED_BREATHING:
      brightness = get_fade_value(&dim_direction, brightness, 1, 10, 85);
      pixels.setBrightness(brightness);
      pixels.fill(pixels.Color(primary_mix, 222, secondary_mix));
      pixels.show();
      delay(30);
      break;

     case FIRE_SPINNING:
      spin_animation(pixels.Color(255, primary_mix, 0));
      break;
     case FIRE_BREATHING:
      brightness = get_fade_value(&dim_direction, brightness, 1, 10, 85);
      pixels.setBrightness(brightness);
      pixels.fill(pixels.Color(255, primary_mix, 0));
      pixels.show();
      delay(30);
      break;
      
     case SPARK_MODE: // Random sparks - just one LED on at a time!
      int i = random(32);
      pixels.setPixelColor(i, RED);
      pixels.show();
      delay(10);
      pixels.setPixelColor(i, pixels.Color(primary_mix, secondary_mix, 222));
      break;

  }

}

void rainbow() {
  static uint16_t j = 0;

  for(byte i=0; i<pixels.numPixels(); i++) 
  {
    pixels.setPixelColor(i, Wheel((i*1+j) & 255));
  }
  pixels.show();

  j++;
  if (j > 256)
  {
    j = 0;
  }
}

uint32_t Wheel(byte WheelPos) {
  if(WheelPos < 85) {
    return pixels.Color(WheelPos * 3, 255 - WheelPos * 3, 0);
  } 
  else if(WheelPos < 170) {
    WheelPos -= 85;
    return pixels.Color(255 - WheelPos * 3, 0, WheelPos * 3);
  } 
  else {
    WheelPos -= 170;
    return pixels.Color(0, WheelPos * 3, 255 - WheelPos * 3);
  }
}


byte get_fade_value(bool *fade_direction, byte value, byte rate, byte min_value, byte max_value)
{
  if (*fade_direction==true)
  {
     value += rate;
     
     //When the end of the fade is reached, switch directions
     if (value > max_value)
     {
        *fade_direction = false;
     }
  }
  else
  {
     value -= rate;
     
     //When the end of the fade is reached, switch directions
     if (value <= min_value)
     {
        *fade_direction=true;
     }
  }

  return value;
}

void spin_animation(uint32_t color)
{
  static uint8_t offset = 0;

  for(int i=1; i<7; i++) 
  {
    uint32_t c = 0;
    if(((offset + i) & 7) < 2) c = color; // 4 pixels on...
    pixels.setPixelColor(   i, c);
  }
  pixels.show();
  offset++;
  delay(50);
}

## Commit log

2021-06-23 3D files
    [cortana_ai_chip_stand.scad, cortana_ai_chip_stand_bottom.stl, cortana_ai_chip_stand_top.stl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]
2021-06-23 Arduino files
2021-06-24 Magnet breakout pcb
    [magnet_wiring_breakout.brd, magnet_wiring_breakout.sch]
2021-08-24 Attiny ring design
    [attiny_cortana.brd, attiny_cortana.sch, attiny_cortana_BOM.xlsx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]
2021-12-14 3D parts for D1 Mini and magnet connector
    [cortana_ai_chip_stand.scad, cortana_ai_chip_stand_bottom.stl, cortana_ai_chip_stand_top.stl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]
2022-07-11 attiny stand
    [attiny_cortana_ai_chip_stand.stl, attiny_cortana_ai_chip_stand_bottom.stl, attiny_cortana_ai_chip_stand_top.stl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]

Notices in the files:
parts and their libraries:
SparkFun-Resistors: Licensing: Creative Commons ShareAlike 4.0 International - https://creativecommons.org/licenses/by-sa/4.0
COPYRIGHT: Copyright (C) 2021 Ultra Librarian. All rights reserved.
